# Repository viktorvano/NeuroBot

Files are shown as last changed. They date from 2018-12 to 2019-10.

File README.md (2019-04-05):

# NeuroBot
This is open source robot with a deep neural network.
Deep Neural Network can be configured by a file content.

Training Data are in "training.txt".

Topology is in "topology.txt".

Demo video: https://www.youtube.com/watch?v=UL9_z_reCno

Android App: https://play.google.com/store/apps/details?id=com.cyberpunktech.RobotController.app

If the content of "weights.txt" file is deleted, the neural network automatically retrain itself again.
If the number of weights in the weights.txt file matches with topology, the Neural Network just loads them, and runs.

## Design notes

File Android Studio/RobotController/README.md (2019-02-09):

Android BluetoothLeGatt Sample
===================================

This sample demonstrates how to use the Bluetooth LE Generic Attribute Profile (GATT)
to transmit arbitrary data between devices.

Introduction
------------

This sample shows a list of available Bluetooth LE devices and provides
an interface to connect, display data and display GATT services and
characteristics supported by the devices.

It creates a [Service][1] for managing connection and data communication with a GATT server
hosted on a given Bluetooth LE device.

The Activities communicate with the Service, which in turn interacts with the [Bluetooth LE API][2].

[1]:http://developer.android.com/reference/android/app/Service.html
[2]:https://developer.android.com/reference/android/bluetooth/BluetoothGatt.html

Pre-requisites
--------------

- Android Compile SDK: API 26
- Android Build Tools v26.0.0
- Android Min Sdk Version: API 18
- Android Support Repository

Screenshots
-------------

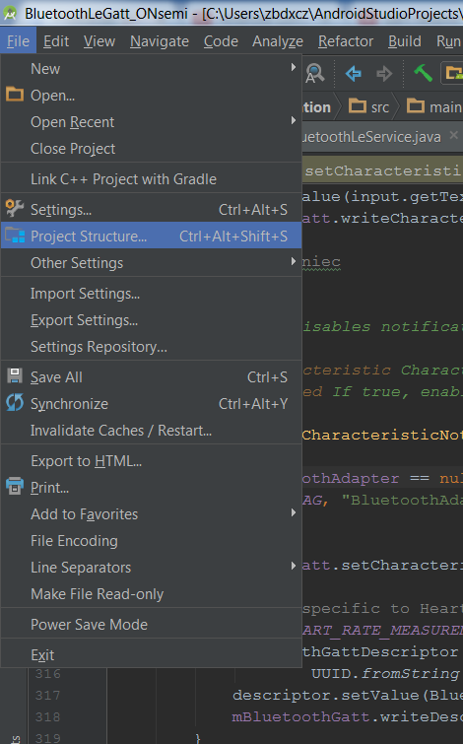
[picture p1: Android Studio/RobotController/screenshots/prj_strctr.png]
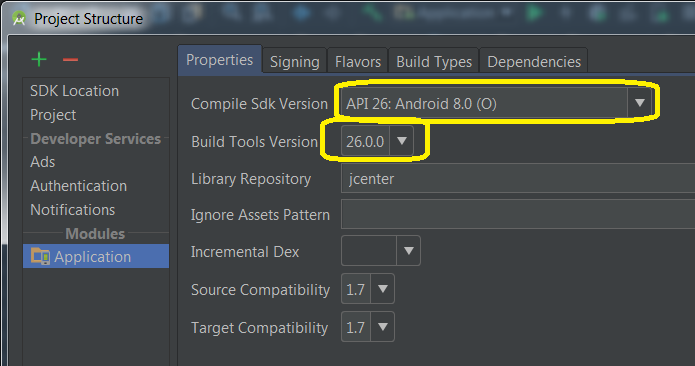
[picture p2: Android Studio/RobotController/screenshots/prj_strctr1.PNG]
 

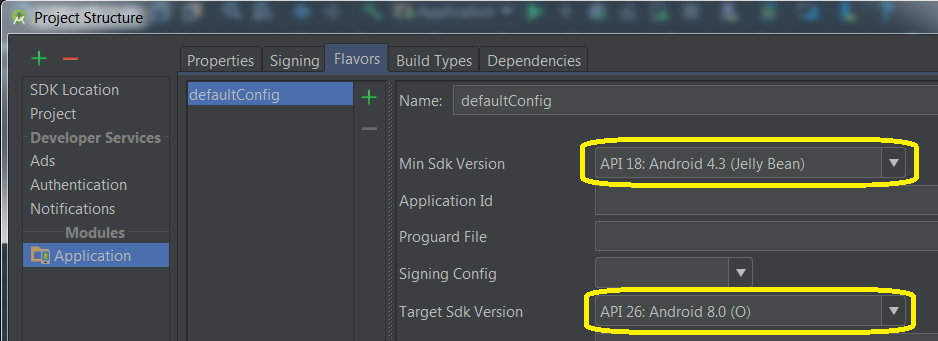
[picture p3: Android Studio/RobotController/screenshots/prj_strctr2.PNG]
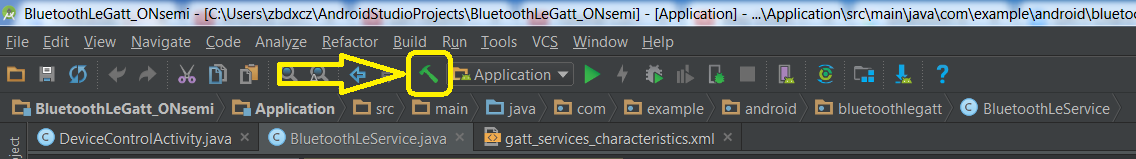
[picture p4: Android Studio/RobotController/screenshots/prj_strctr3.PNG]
 

Getting Started
---------------

This sample uses the Gradle build system. To build this project, use the
"gradlew build" command or use "Import Project" in Android Studio.

Support
-------

- Google+ Community: https://plus.google.com/communities/105153134372062985968
- Stack Overflow: http://stackoverflow.com/questions/tagged/android

Source code origin:
https://github.com/googlesamples/android-BluetoothLeGatt

Patches are encouraged, and may be submitted by forking this project and
submitting a pull request through GitHub. Please see CONTRIBUTING.md for more details.

License
-------

Copyright 2017 The Android Open Source Project, Inc.

Licensed to the Apache Software Foundation (ASF) under one or more contributor
license agreements.  See the NOTICE file distributed with this work for
additional information regarding copyright ownership.  The ASF licenses this
file to you under the Apache License, Version 2.0 (the "License"); you may not
use this file except in compliance with the License.  You may obtain a copy of
the License at

http://www.apache.org/licenses/LICENSE-2.0

Unless required by applicable law or agreed to in writing, software
distributed under the License is distributed on an "AS IS" BASIS, WITHOUT
WARRANTIES OR CONDITIONS OF ANY KIND, either express or implied.  See the
License for the specific language governing permissions and limitations under
the License.

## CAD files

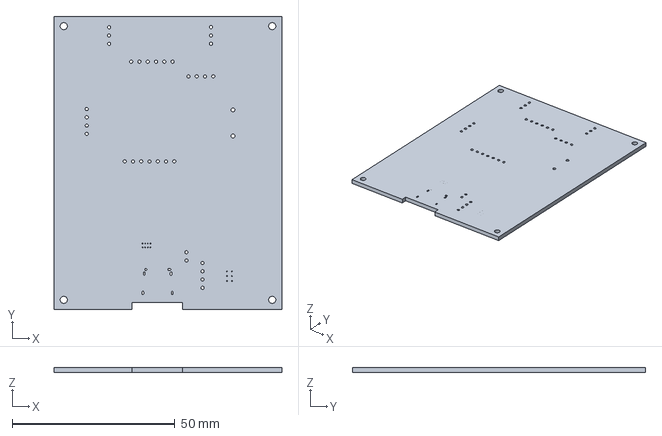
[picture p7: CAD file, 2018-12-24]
KiCad/Neural Robot/NeuralRobot.step
70.0 x 90.0 x 1.60 mm

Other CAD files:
FreeCad/NeuroBot.step
FreeCad/NeuroBot.FCStd
FreeCad/NeuroBot.stl

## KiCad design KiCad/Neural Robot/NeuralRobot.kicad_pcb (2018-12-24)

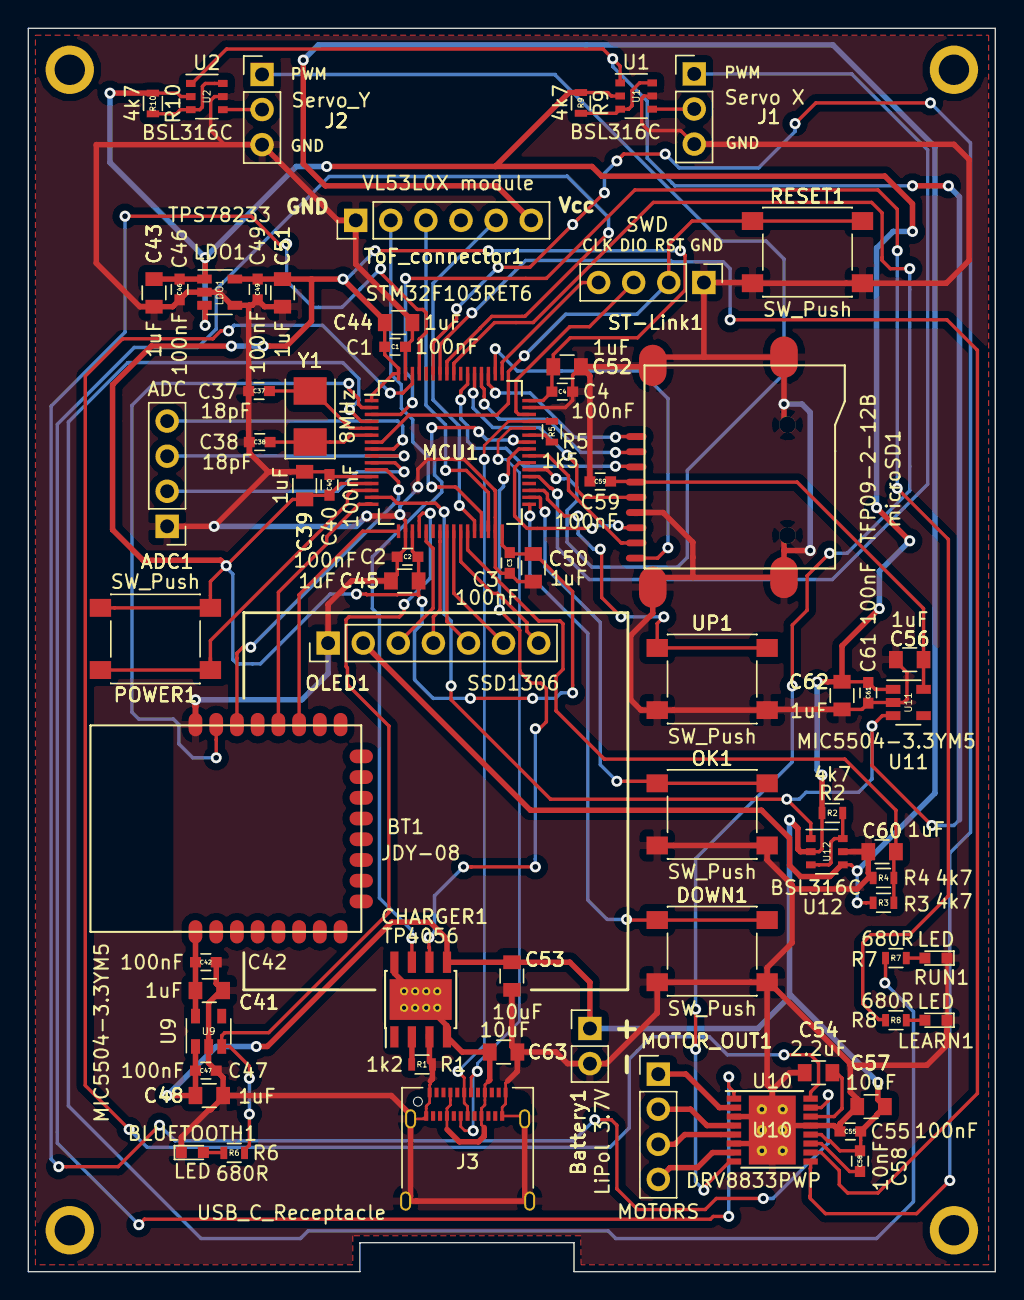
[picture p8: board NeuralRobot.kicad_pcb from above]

Board: 2 copper layers, 70.0 x 90.0 mm, 70 parts (0 on the bottom side), 71 nets.

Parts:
ADC1: ADC; Socket_Strip_Straight_1x04_Pitch2.54mm
BLUETOOTH1: LED; LED_0603
BT1: JDY-08; JDY-08_module
Battery1: LiPol 3.7V; Socket_Strip_Straight_1x02_Pitch2.54mm
C1, C2, C3, C4, C40, C42, C46, C47, C49, C55, C59, C61: 100nF; C_0603
C37, C38: 18pF; C_0603
C39, C41, C43, C44, C45, C48, C50, C51, C52, C56, C60, C62: 1uF; C_0805
C53, C57, C63: 10uF; C_0805
C54: 2.2uF; C_0805
C58: 10nF; C_0603
CHARGER1: TP4056; HTSOP-8-1EP_3.9x4.9mm_Pitch1.27mm_ThermalVias_LargeCopper
DOWN1: SW_Push; SW_SPST_PTS645
J1: Servo X; Socket_Strip_Straight_1x03_Pitch2.54mm
J2: Servo_Y; Socket_Strip_Straight_1x03_Pitch2.54mm
J3: USB_C_Receptacle; USB_C_Receptacle_Amphenol_12401610E4-2A
LDO1: TPS78233; SOT-23-5
LEARN1: LED; LED_0603
MCU1: STM32F103RET6; LQFP-64_10x10mm_Pitch0.5mm
MOTOR_OUT1: MOTORS; Socket_Strip_Straight_1x04_Pitch2.54mm
OK1: SW_Push; SW_SPST_PTS645
OLED1: SSD1306; Socket_Strip_Straight_1x07_Pitch2.54mm
POWER1: SW_Push; SW_SPST_PTS645
R1: 1k2; R_0603
R2, R3, R4, R9, R10: 4k7; R_0603
R5: 1k5; R_0603
R6, R7, R8: 680R; R_0603
RESET1: SW_Push; SW_SPST_PTS645
RUN1: LED; LED_0603
ST-Link1: SWD; Socket_Strip_Straight_1x04_Pitch2.54mm
ToF_connector1: VL53L0X module; Socket_Strip_Straight_1x06_Pitch2.54mm
U1, U2, U12: BSL316C; TSOP-6_1.65x3.05mm_Pitch0.95mm
U9, U11: MIC5504-3.3YM5; SOT-23-5
U10: DRV8833PWP; HTSSOP-16-1EP_4.4x5mm_Pitch0.65mm_ThermalVias
UP1: SW_Push; SW_SPST_PTS645
Y1: 8MHz; Crystal_SMD_5032-2pin_5.0x3.2mm
microSD1: TFP09-2-12B; microSD_card_slot

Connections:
3V3_STM32: C1.2, C2.1, C3.1, C4.1, C39.2, C40.1, C44.2, C45.2, C49.2, C50.2, C51.2, C52.2, LDO1.5, MCU1.1, MCU1.13, MCU1.19, MCU1.32, MCU1.48, MCU1.64, POWER1.2
3V7: Battery1.1, C43.2, C46.2, C47.2, C48.2, C53.2, C55.1, C57.1, C58.2, C61.2, C62.2, CHARGER1.5, LDO1.1, LDO1.3, R2.1, R9.1, R10.1, U1.2, U2.2, U9.1, U10.12, U11.1, U12.2
5V: C63.2, CHARGER1.4, CHARGER1.8, CHARGER1.9, J3.A4, J3.A9, J3.B4, J3.B9
A1: MCU1.62, U10.16
A2: MCU1.61, U10.15
B1: MCU1.59, U10.9
B2: MCU1.58, U10.10
BATTERY_SENSE: C60.2, MCU1.27, R3.1, R4.2
BT_ENABLE: MCU1.20, R6.2, U9.3
BT_PWR: BT1.22, MCU1.11
BT_RST: BT1.23, MCU1.2
BT_Vcc: BT1.1, C41.2, C42.2, U9.5
BUTTON_DOWN: DOWN1.1, MCU1.33
BUTTON_OK: MCU1.34, OK1.1
BUTTON_UP: MCU1.35, UP1.1
CHARGING: CHARGER1.7, MCU1.42
CS: MCU1.26, OLED1.7
D+: J3.A6, J3.B6, MCU1.45, R5.1
D-: J3.A7, J3.B7, MCU1.44
DC: MCU1.25, OLED1.6
FULL: CHARGER1.6, MCU1.41
GND: ADC1.1, BLUETOOTH1.1, BT1.24, Battery1.2, C1.1, C2.2, C3.2, C4.2, C37.2, C38.2, C39.1, C40.2, C41.1, C42.1, C43.1, C44.1, C45.1, C46.1, C47.1, C48.1, C49.1, C50.1, C51.1, C52.1, C53.1, C54.2, C55.2, C56.1, C57.2, C59.1, C60.1, C61.1, C62.1, C63.1, CHARGER1.3, DOWN1.2, J1.3, J2.3, J3.A1, J3.A12, J3.B1, J3.B12, J3.S1, LDO1.2, LDO1.4, LEARN1.1, MCU1.12, MCU1.18, MCU1.31, MCU1.47, MCU1.63, OK1.2, OLED1.1, R1.2, R4.1, RESET1.2, RUN1.1, ST-Link1.1, ToF_connector1.1, U1.5, U2.5, U9.2, U10.3, U10.6, U10.13, U10.17, U11.2, U12.5, UP1.2, microSD1.6, microSD1.10
LED_RUN: MCU1.4, R7.2
LED_TRAINING: MCU1.3, R8.2
MOSFET_ENABLE: MCU1.15, U1.1, U2.1, U11.3, U12.1
MOSFET_OUT: OLED1.2, R3.2, ToF_connector1.6, U12.4
MOSI: MCU1.23, OLED1.4
MOTORS_ENABLE: MCU1.57, U10.1
unnamed: ADC1.2, MCU1.10
unnamed: ADC1.3, MCU1.9
unnamed: ADC1.4, MCU1.8
unnamed: BLUETOOTH1.2, R6.1
unnamed: C37.1, MCU1.5, Y1.2
unnamed: C38.1, MCU1.6, Y1.1
unnamed: C54.1, U10.14
unnamed: CHARGER1.2, R1.1
unnamed: J1.2, U1.4
unnamed: J2.2, U2.4
unnamed: LEARN1.2, R8.1
unnamed: MOTOR_OUT1.1, U10.2
unnamed: MOTOR_OUT1.2, U10.4
unnamed: MOTOR_OUT1.4, U10.7
unnamed: R2.2, U12.3, U12.6
unnamed: R7.1, RUN1.2
unnamed: R9.2, U1.3, U1.6
unnamed: R10.2, U2.3, U2.6
OUT2: MOTOR_OUT1.3, U10.5
PA0: MCU1.14, POWER1.1
PWM_X: J1.1, MCU1.37
PWM_Y: J2.1, MCU1.38
RST: MCU1.24, OLED1.5
RX: BT1.19, MCU1.17
Reset: MCU1.7, RESET1.1, ST-Link1.2
SCK: MCU1.21, OLED1.3
SCL: MCU1.29, ToF_connector1.2
SDA: MCU1.30, ToF_connector1.3
SDIO_CLK: MCU1.53, microSD1.5
SDIO_CMD: MCU1.54, microSD1.3
SDIO_D0: MCU1.39, microSD1.7
SDIO_D1: MCU1.40, microSD1.8
SDIO_D2: MCU1.51, microSD1.1
SDIO_D3: MCU1.52, microSD1.2
SD_DETECTION: MCU1.50, microSD1.9
SD_Vcc: C56.2, C59.2, U11.5, microSD1.4
SWCLK: MCU1.49, ST-Link1.4
SWDIO: MCU1.46, ST-Link1.3
TX: BT1.20, MCU1.16
ToF_Enable: MCU1.28, ToF_connector1.5
USB_ENABLE: MCU1.43, R5.2
VCP: C58.1, U10.11
nFAULT: MCU1.56, U10.8

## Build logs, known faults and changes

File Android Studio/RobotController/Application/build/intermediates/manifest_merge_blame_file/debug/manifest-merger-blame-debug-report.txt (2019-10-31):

1<?xml version="1.0" encoding="utf-8"?>
2<!--
3 Copyright 2013 The Android Open Source Project
4
5 Licensed under the Apache License, Version 2.0 (the "License");
6 you may not use this file except in compliance with the License.
7 You may obtain a copy of the License at
8
9     http://www.apache.org/licenses/LICENSE-2.0
10
11 Unless required by applicable law or agreed to in writing, software
12 distributed under the License is distributed on an "AS IS" BASIS,
13 WITHOUT WARRANTIES OR CONDITIONS OF ANY KIND, either express or implied.
14 See the License for the specific language governing permissions and
15 limitations under the License.
16-->
17<manifest xmlns:android="http://schemas.android.com/apk/res/android"
18    package="com.cyberpunktech.RobotController.app"
19    android:versionCode="7"
20    android:versionName="1.6" >
21
22    <uses-sdk
23        android:minSdkVersion="18"
23-->C:\Users\viktor.vano\Documents\GitHub\NeuroBot\Android Studio\RobotController\Application\src\main\AndroidManifest.xml
24        android:targetSdkVersion="28" />
24-->C:\Users\viktor.vano\Documents\GitHub\NeuroBot\Android Studio\RobotController\Application\src\main\AndroidManifest.xml
25
26    <!-- Min/target SDK versions (<uses-sdk>) managed by build.gradle -->
27
28
29    <!--
30    Declare this required feature if you want to make the app available to BLE-capable
31    devices only.  If you want to make your app available to devices that don't support BLE,
32    you should omit this in the manifest.  Instead, determine BLE capability by using
33    PackageManager.hasSystemFeature(FEATURE_BLUETOOTH_LE)
34    -->
35    <uses-feature
35-->C:\Users\viktor.vano\Documents\GitHub\NeuroBot\Android Studio\RobotController\Application\src\main\AndroidManifest.xml:31:5-89
36        android:name="android.hardware.bluetooth_le"
36-->C:\Users\viktor.vano\Documents\GitHub\NeuroBot\Android Studio\RobotController\Application\src\main\AndroidManifest.xml:31:19-63
37        android:required="true" />
37-->C:\Users\viktor.vano\Documents\GitHub\NeuroBot\Android Studio\RobotController\Application\src\main\AndroidManifest.xml:31:64-87
38
39    <uses-permission android:name="android.permission.BLUETOOTH" />
39-->C:\Users\viktor.vano\Documents\GitHub\NeuroBot\Android Studio\RobotController\Application\src\main\AndroidManifest.xml:33:5-67
39-->C:\Users\viktor.vano\Documents\GitHub\NeuroBot\Android Studio\RobotController\Application\src\main\AndroidManifest.xml:33:22-65
40    <uses-permission android:name="android.permission.BLUETOOTH_ADMIN" />
40-->C:\Users\viktor.vano\Documents\GitHub\NeuroBot\Android Studio\RobotController\Application\src\main\AndroidManifest.xml:34:5-73
40-->C:\Users\viktor.vano\Documents\GitHub\NeuroBot\Android Studio\RobotController\Application\src\main\AndroidManifest.xml:34:22-71
41    <uses-permission android:name="android.permission.ACCESS_COARSE_LOCATION" />
41-->C:\Users\viktor.vano\Documents\GitHub\NeuroBot\Android Studio\RobotController\Application\src\main\AndroidManifest.xml:35:5-81
41-->C:\Users\viktor.vano\Documents\GitHub\NeuroBot\Android Studio\RobotController\Application\src\main\AndroidManifest.xml:35:22-78
42    <uses-permission android:name="android.permission.ACCESS_FINE_LOCATION" />
42-->C:\Users\viktor.vano\Documents\GitHub\NeuroBot\Android Studio\RobotController\Application\src\main\AndroidManifest.xml:36:5-79
42-->C:\Users\viktor.vano\Documents\GitHub\NeuroBot\Android Studio\RobotController\Application\src\main\AndroidManifest.xml:36:22-76
43
44    <application
44-->C:\Users\viktor.vano\Documents\GitHub\NeuroBot\Android Studio\RobotController\Application\src\main\AndroidManifest.xml:40:5-56:19
45        android:appComponentFactory="android.support.v4.app.CoreComponentFactory"
45-->[com.android.support:support-compat:28.0.0] C:\Users\viktor.vano\.gradle\caches\transforms-2\files-2.1\ccf94a4f227dfa4f17156620e28a8b98\support-compat-28.0.0\AndroidManifest.xml:22:18-91
46        android:debuggable="true"
47        android:icon="@drawable/ic_launcher"
47-->C:\Users\viktor.vano\Documents\GitHub\NeuroBot\Android Studio\RobotController\Application\src\main\AndroidManifest.xml:41:9-45
48        android:label="Robot Controller"
48-->C:\Users\viktor.vano\Documents\GitHub\NeuroBot\Android Studio\RobotController\Application\src\main\AndroidManifest.xml:40:18-50
49        android:testOnly="true"
50        android:theme="@android:style/Theme.Holo.Light" >
50-->C:\Users\viktor.vano\Documents\GitHub\NeuroBot\Android Studio\RobotController\Application\src\main\AndroidManifest.xml:42:9-56
51        <activity
51-->C:\Users\viktor.vano\Documents\GitHub\NeuroBot\Android Studio\RobotController\Application\src\main\AndroidManifest.xml:43:9-51:20
52            android:name="com.cyberpunktech.RobotController.app.DeviceScanActivity"
52-->C:\Users\viktor.vano\Documents\GitHub\NeuroBot\Android Studio\RobotController\Application\src\main\AndroidManifest.xml:43:19-90
53            android:configChanges="orientation"
53-->C:\Users\viktor.vano\Documents\GitHub\NeuroBot\Android Studio\RobotController\Application\src\main\AndroidManifest.xml:45:13-48
54            android:label="Robot Controller"
54-->C:\Users\viktor.vano\Documents\GitHub\NeuroBot\Android Studio\RobotController\Application\src\main\AndroidManifest.xml:44:13-45
55            android:screenOrientation="portrait" >
55-->C:\Users\viktor.vano\Documents\GitHub\NeuroBot\Android Studio\RobotController\Application\src\main\AndroidManifest.xml:46:13-49
56            <intent-filter>
56-->C:\Users\viktor.vano\Documents\GitHub\NeuroBot\Android Studio\RobotController\Application\src\main\AndroidManifest.xml:47:13-50:29
57                <action android:name="android.intent.action.MAIN" />
57-->C:\Users\viktor.vano\Documents\GitHub\NeuroBot\Android Studio\RobotController\Application\src\main\AndroidManifest.xml:48:17-68
57-->C:\Users\viktor.vano\Documents\GitHub\NeuroBot\Android Studio\RobotController\Application\src\main\AndroidManifest.xml:48:25-66
58
59                <category android:name="android.intent.category.LAUNCHER" />
59-->C:\Users\viktor.vano\Documents\GitHub\NeuroBot\Android Studio\RobotController\Application\src\main\AndroidManifest.xml:49:17-76
59-->C:\Users\viktor.vano\Documents\GitHub\NeuroBot\Android Studio\RobotController\Application\src\main\AndroidManifest.xml:49:27-74
60            </intent-filter>
61        </activity>
62        <activity
62-->C:\Users\viktor.vano\Documents\GitHub\NeuroBot\Android Studio\RobotController\Application\src\main\AndroidManifest.xml:52:9-54:51
63            android:name="com.cyberpunktech.RobotController.app.DeviceControlActivity"
63-->C:\Users\viktor.vano\Documents\GitHub\NeuroBot\Android Studio\RobotController\Application\src\main\AndroidManifest.xml:52:19-93
64            android:configChanges="orientation"
64-->C:\Users\viktor.vano\Documents\GitHub\NeuroBot\Android Studio\RobotController\Application\src\main\AndroidManifest.xml:53:13-48
65            android:screenOrientation="portrait" />
65-->C:\Users\viktor.vano\Documents\GitHub\NeuroBot\Android Studio\RobotController\Application\src\main\AndroidManifest.xml:54:13-49
66
67        <service
67-->C:\Users\viktor.vano\Documents\GitHub\NeuroBot\Android Studio\RobotController\Application\src\main\AndroidManifest.xml:55:9-114
68            android:name="com.cyberpunktech.RobotController.app.BluetoothLeService"
68-->C:\Users\viktor.vano\Documents\GitHub\NeuroBot\Android Studio\RobotController\Application\src\main\AndroidManifest.xml:55:18-89
69            android:enabled="true" />
69-->C:\Users\viktor.vano\Documents\GitHub\NeuroBot\Android Studio\RobotController\Application\src\main\AndroidManifest.xml:55:90-112
70    </application>
71
72</manifest>

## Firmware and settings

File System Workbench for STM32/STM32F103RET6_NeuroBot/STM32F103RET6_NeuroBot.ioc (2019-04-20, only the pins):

Mcu.UserName=STM32F103RETx
PA0-WKUP.GPIO_Label=POWER_ON_MAIN
PA0-WKUP.Signal=SYS_WKUP
PA1.GPIO_Label=MOSFET_Enable
PA1.Signal=GPIO_Output
PA10.GPIO_Label=USB_Enable
PA10.Signal=GPIO_Output
PA11.Signal=USB_DM
PA12.Signal=USB_DP
PA13.Signal=SYS_JTMS-SWDIO
PA14.Signal=SYS_JTCK-SWCLK
PA15.GPIO_Label=SD_DETECTION
PA15.Signal=GPIO_Input
PA2.Signal=USART2_TX
PA3.Signal=USART2_RX
PA4.GPIO_Label=Bluetooth_Enable
PA4.Signal=GPIO_Output
PA5.Signal=SPI1_SCK
PA7.Signal=SPI1_MOSI
PA8.GPIO_Label=Battery_Full
PA8.Signal=GPIO_Input
PA9.GPIO_Label=Battery_Charging
PA9.Signal=GPIO_Input
PB0.GPIO_Label=OLED_CS
PB0.Signal=GPIO_Output
PB1.GPIO_Label=BATTERY_SENSE
PB1.Signal=ADCx_IN9
PB10.Signal=I2C2_SCL
PB11.Signal=I2C2_SDA
PB12.GPIO_Label=BUTTON_DOWN
PB12.Signal=GPIO_Input
PB13.GPIO_Label=BUTTON_OK
PB13.Signal=GPIO_Input
PB14.GPIO_Label=BUTTON_UP
PB14.Signal=GPIO_Input
PB2.GPIO_Label=ToF_Enable
PB2.Signal=GPIO_Output
PB4.GPIO_Label=Motor_nFault
PB4.Signal=GPIO_Input
PB5.GPIO_Label=Motor_Enable
PB5.Signal=GPIO_Output
PB6.GPIO_Label=Motor_B2
PB6.Signal=GPIO_Output
PB7.GPIO_Label=Motor_B1
PB7.Signal=GPIO_Output
PB8.GPIO_Label=Motor_A2
PB8.Signal=GPIO_Output
PB9.GPIO_Label=Motor_A1
PB9.Signal=GPIO_Output
PC0.Signal=ADCx_IN10
PC1.Signal=ADCx_IN11
PC10.Signal=SDIO_D2
PC11.Signal=SDIO_D3
PC12.Signal=SDIO_CK
PC13-TAMPER-RTC.GPIO_Label=Bluetooth_RESET
PC13-TAMPER-RTC.Signal=GPIO_Output
PC14-OSC32_IN.GPIO_Label=LED_Training
PC14-OSC32_IN.Signal=GPIO_Output
PC15-OSC32_OUT.GPIO_Label=LED_Run
PC15-OSC32_OUT.Signal=GPIO_Output
PC2.Signal=ADCx_IN12
PC3.GPIO_Label=Bluetooth_PWR
PC3.Signal=GPIO_Output
PC4.GPIO_Label=OLED_RESET
PC4.Signal=GPIO_Output
PC5.GPIO_Label=OLED_DC
PC5.Signal=GPIO_Output
PC6.Signal=S_TIM3_CH1
PC7.Signal=S_TIM3_CH2
PC8.Signal=SDIO_D0
PC9.Signal=SDIO_D1
PD0-OSC_IN.Signal=RCC_OSC_IN
PD1-OSC_OUT.Signal=RCC_OSC_OUT
PD2.Signal=SDIO_CMD

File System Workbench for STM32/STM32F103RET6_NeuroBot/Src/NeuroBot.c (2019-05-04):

/*
 * NeuroBot.c
 *
 *  Created on: Dec 5, 2018
 *      Author: CyberPunkTECH
 */

#include "NeuroBot.h"


char buffer[50];
ButtonStruct OK, UP, DOWN, POWER;
int iDistance;
int model=0, revision=0;
uint8_t menu=0, redraw=1, cnt_flag=0;
uint32_t ADC[4];
float Battery=2500;
int percent=100, percent_old;
FATFS myFAT;
uint16_t connection_cnt=1000, cnt_20ms=250;

void NeuroBot_init()
{
	HAL_TIM_Base_Start(&htim3);
	servoX(0.5f);
	servoY(0.0f);
	HAL_TIM_PWM_Start(&htim3, TIM_CHANNEL_1);
	HAL_TIM_PWM_Start(&htim3, TIM_CHANNEL_2);

	HAL_GPIO_WritePin(MOSFET_Enable_GPIO_Port, MOSFET_Enable_Pin, SET);
	HAL_GPIO_WritePin(ToF_Enable_GPIO_Port, ToF_Enable_Pin, SET);
	while(I2C2->SR2==2)
	{
	  while(HAL_I2C_DeInit(&hi2c2)!=HAL_OK);
	  while(HAL_I2C_Init(&hi2c2)!=HAL_OK);
	}
	tofInit(1); // set long range mode (up to 2m)
	tofGetModel(&model, &revision);
	iDistance = tofReadDistance();
	while(model!=238 || revision!=16)
	{
	  while(HAL_I2C_DeInit(&hi2c2)!=HAL_OK);
	  while(HAL_I2C_Init(&hi2c2)!=HAL_OK);
	  tofInit(1); // set long range mode (up to 2m)
	  tofGetModel(&model, &revision);
	  iDistance = tofReadDistance();
	}
	HAL_TIM_Base_Start_IT(&htim2);

	HAL_ADC_Start_DMA(&hadc1, (uint32_t*)ADC,4);
	HAL_ADC_Start_IT(&hadc1);

	ssd1306_Init();
	ssd1306_Fill(Black);
	ssd1306_SetCursor(30, 0);
	ssd1306_WriteString("Hello", Font_11x18, White);
	ssd1306_SetCursor(35, 20);
	ssd1306_WriteString("I am", Font_11x18, White);
	ssd1306_SetCursor(20, 40);
	ssd1306_WriteString("NeuroBot", Font_11x18, White);
	ssd1306_UpdateScreen();

	memset(buffer, 0, sizeof(buffer));
	__HAL_UART_DISABLE_IT(&huart2, UART_IT_RXNE);
	GPIO_POWER_Init();
	HAL_Delay(2000);
	buttons_release();

	HAL_GPIO_WritePin(Motor_Enable_GPIO_Port, Motor_Enable_Pin, SET);
	HAL_GPIO_WritePin(Bluetooth_Enable_GPIO_Port, Bluetooth_Enable_Pin, RESET);
	HAL_GPIO_WritePin(LED_Training_GPIO_Port, LED_Training_Pin, RESET);
	HAL_GPIO_WritePin(LED_Run_GPIO_Port, LED_Run_Pin, RESET);
	if(!HAL_GPIO_ReadPin(SD_DETECTION_GPIO_Port, SD_DETECTION_Pin))
	{
		int temp=0;
	  hsd.Init.ClockDiv = 36;
	  while(HAL_SD_Init(&hsd, &SDCardInfo)!=SD_OK)
	  {
		  temp++;
		  HAL_Delay(100);
		  if(temp>=30)
			  NeuroBot_sleep();
	  }
	  temp=0;
	  while(HAL_SD_WideBusOperation_Config(&hsd, SDIO_BUS_WIDE_4B))
	  {
		  temp++;
		  HAL_Delay(100);
		  if(temp>=30)
			  NeuroBot_sleep();
	  }
	}else
	{
		ssd1306_Fill(Black);
		ssd1306_SetCursor(2, 26);
		ssd1306_WriteString("Insert SD", Font_11x18, White);
		ssd1306_SetCursor(2, 26+18);
		ssd1306_WriteString("Press OK to OFF.", Font_7x10, White);
		ssd1306_UpdateScreen();
		while(!OK.released);
		NeuroBot_sleep();
	}

	uint8_t attempts=0;
	while(1)
	{
		attempts++;
		if(f_mount(&myFAT, SD_Path, 1)==FR_OK)
			break;
		if(attempts>10)
			NeuroBot_sleep();
		HAL_Delay(150);
	}

	percent_old=percent;
}

void servoY(float value)
{
	if(value<=0.0f)
		value=0.0f;
	__HAL_TIM_SetCompare(&htim3, TIM_CHANNEL_2, 51+(value*52.0f));
}

void servoX(float value)
{
	if(value<=0.0f)
		value=0.0f;
	__HAL_TIM_SetCompare(&htim3, TIM_CHANNEL_1, 33+(value*80.0f));
}

float measure_distance()
{
	iDistance = tofReadDistance();
	if(iDistance>2000)
	{
		iDistance=2000;
	}else
	if(iDistance<0)
	{
		iDistance=0;
	}

	return (float)iDistance/2000.0f;
}

uint8_t string_compare(char array1[], char array2[], uint16_t lenght)
{
	 uint8_t comVAR=0, i;
	 for(i=0;i<lenght;i++)
	   	{
	   		  if(array1[i]==array2[i])
	   	  		  comVAR++;
	   	  	  else comVAR=0;
	   	}
	 if (comVAR==lenght)
		 	return 1;
	 else 	return 0;
}

void Message_handler()
{
	if(string_compare(buffer, "stop", strlen("stop")))
	{
		motor_stop();
	}else
	if(string_compare(buffer, "forward", strlen("forward")))
	{
		motorA_forward();
		motorB_forward();
	}else
	if(string_compare(buffer, "backward", strlen("backward")))
	{
		motorA_backward();
		motorB_backward();
	}else
	if(string_compare(buffer, "right", strlen("right")))
	{
		motorA_forward();
		motorB_backward();
	}else
	if(string_compare(buffer, "left", strlen("left")))
	{
		motorA_backward();
		motorB_forward();
	}
}

void overheat_check()
{
	if(!HAL_GPIO_ReadPin(Motor_nFault_GPIO_Port, Motor_nFault_Pin))//overheat
	{
		HAL_GPIO_WritePin(Motor_A1_GPIO_Port, Motor_A1_Pin, 0);
		HAL_GPIO_WritePin(Motor_A2_GPIO_Port, Motor_A2_Pin, 0);
		HAL_GPIO_WritePin(Motor_B1_GPIO_Port, Motor_B1_Pin, 0);
		HAL_GPIO_WritePin(Motor_B2_GPIO_Port, Motor_B2_Pin, 0);
		ssd1306_Fill(Black);
		ssd1306_SetCursor(30, 0);
		ssd1306_WriteString("Motor", Font_11x18, White);
		ssd1306_SetCursor(35, 20);
		ssd1306_WriteString("driver", Font_11x18, White);
		ssd1306_SetCursor(20, 40);
		ssd1306_WriteString("overheat", Font_11x18, White);
		ssd1306_UpdateScreen();
		while(!HAL_GPIO_ReadPin(Motor_nFault_GPIO_Port, Motor_nFault_Pin));
	}
}

void motor_stop()
{
	  HAL_GPIO_WritePin(Motor_A1_GPIO_Port, Motor_A1_Pin, 0);
	  HAL_GPIO_WritePin(Motor_A2_GPIO_Port, Motor_A2_Pin, 0);
	  HAL_GPIO_WritePin(Motor_B1_GPIO_Port, Motor_B1_Pin, 0);
	  HAL_GPIO_WritePin(Motor_B2_GPIO_Port, Motor_B2_Pin, 0);
	  overheat_check();
}

void motorA_forward()
{
	  HAL_GPIO_WritePin(Motor_A1_GPIO_Port, Motor_A1_Pin, 1);
	  HAL_GPIO_WritePin(Motor_A2_GPIO_Port, Motor_A2_Pin, 0);
}

void motorA_backward()
{
	  HAL_GPIO_WritePin(Motor_A1_GPIO_Port, Motor_A1_Pin, 0);
	  HAL_GPIO_WritePin(Motor_A2_GPIO_Port, Motor_A2_Pin, 1);
}

void motorA_stop()
{
	  HAL_GPIO_WritePin(Motor_A1_GPIO_Port, Motor_A1_Pin, 0);
	  HAL_GPIO_WritePin(Motor_A2_GPIO_Port, Motor_A2_Pin, 0);
}

void motorB_forward()
{
	  HAL_GPIO_WritePin(Motor_B1_GPIO_Port, Motor_B1_Pin, 1);
	  HAL_GPIO_WritePin(Motor_B2_GPIO_Port, Motor_B2_Pin, 0);
}

void motorB_backward()
{
	  HAL_GPIO_WritePin(Motor_B1_GPIO_Port, Motor_B1_Pin, 0);
	  HAL_GPIO_WritePin(Motor_B2_GPIO_Port, Motor_B2_Pin, 1);
}

void motorB_stop()
{
	  HAL_GPIO_WritePin(Motor_B1_GPIO_Port, Motor_B1_Pin, 0);
	  HAL_GPIO_WritePin(Motor_B2_GPIO_Port, Motor_B2_Pin, 0);
}
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

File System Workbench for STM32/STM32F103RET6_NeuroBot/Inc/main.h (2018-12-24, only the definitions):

#define Bluetooth_RESET_Pin GPIO_PIN_13
#define Bluetooth_RESET_GPIO_Port GPIOC
#define LED_Training_Pin GPIO_PIN_14
#define LED_Training_GPIO_Port GPIOC
#define LED_Run_Pin GPIO_PIN_15
#define LED_Run_GPIO_Port GPIOC
#define Bluetooth_PWR_Pin GPIO_PIN_3
#define Bluetooth_PWR_GPIO_Port GPIOC
#define POWER_ON_MAIN_Pin GPIO_PIN_0
#define POWER_ON_MAIN_GPIO_Port GPIOA
#define MOSFET_Enable_Pin GPIO_PIN_1
#define MOSFET_Enable_GPIO_Port GPIOA
#define Bluetooth_Enable_Pin GPIO_PIN_4
#define Bluetooth_Enable_GPIO_Port GPIOA
#define OLED_RESET_Pin GPIO_PIN_4
#define OLED_RESET_GPIO_Port GPIOC
#define OLED_DC_Pin GPIO_PIN_5
#define OLED_DC_GPIO_Port GPIOC
#define OLED_CS_Pin GPIO_PIN_0
#define OLED_CS_GPIO_Port GPIOB
#define BATTERY_SENSE_Pin GPIO_PIN_1
#define BATTERY_SENSE_GPIO_Port GPIOB
#define ToF_Enable_Pin GPIO_PIN_2
#define ToF_Enable_GPIO_Port GPIOB
#define BUTTON_DOWN_Pin GPIO_PIN_12
#define BUTTON_DOWN_GPIO_Port GPIOB
#define BUTTON_OK_Pin GPIO_PIN_13
#define BUTTON_OK_GPIO_Port GPIOB
#define BUTTON_UP_Pin GPIO_PIN_14
#define BUTTON_UP_GPIO_Port GPIOB
#define Battery_Full_Pin GPIO_PIN_8
#define Battery_Full_GPIO_Port GPIOA
#define Battery_Charging_Pin GPIO_PIN_9
#define Battery_Charging_GPIO_Port GPIOA
#define USB_Enable_Pin GPIO_PIN_10
#define USB_Enable_GPIO_Port GPIOA
#define SD_DETECTION_Pin GPIO_PIN_15
#define SD_DETECTION_GPIO_Port GPIOA
#define Motor_nFault_Pin GPIO_PIN_4
#define Motor_nFault_GPIO_Port GPIOB
#define Motor_Enable_Pin GPIO_PIN_5
#define Motor_Enable_GPIO_Port GPIOB
#define Motor_B2_Pin GPIO_PIN_6
#define Motor_B2_GPIO_Port GPIOB
#define Motor_B1_Pin GPIO_PIN_7
#define Motor_B1_GPIO_Port GPIOB
#define Motor_A2_Pin GPIO_PIN_8
#define Motor_A2_GPIO_Port GPIOB
#define Motor_A1_Pin GPIO_PIN_9
#define Motor_A1_GPIO_Port GPIOB

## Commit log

2018-12-24 First upload
    it contains Cpp project for Visual Studio, System Workbench, and PCB project for KiCad
    [HC06.xlsx, Neural Robot-2018-09-08-19-01-07.sch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]
2018-12-25 Updated projects, added FreCad
    Added FreeCad project, updated Android App, and SWforSTM32.
    Now it sends a message via Bluetooth every 100 ms.
    [NeuroBot.FCStd, NeuroBot.step, NeuroBot.stl]
2018-12-25 3D model update
    Updated FreeCad 3D model for NeuroBot.
    [NeuroBot.FCStd, NeuroBot.step, NeuroBot.stl]
2019-01-11 STM code update
    Updated code for NeuroBot for STM32.
2019-01-11 Updated Freecad Model
    Now it fits well.
    [NeuroBot.FCStd, NeuroBot.step, NeuroBot.stl]
2019-01-11 Updated battery
    Updated max battery level condition.
2019-01-12 Updated battery code
    Now it shows a battery accurately.
2019-01-12 Battery update
    Better coeficient, to calculate voltage.
2019-01-21 Fall detection
    Now it tilts down ToF sensor to avoid a fall from the edge.
    [NeuroBot.c]
2019-01-30 Android update
    Now BLE scan, works on new Android devices.
2019-02-04 Servo tuning
    I just tuned the X servo to the middle.
2019-02-10 FIxed DMA and Battery issue
    I forgot to add 4th ADC to DMA, so those ADC measurements were mixing in a bigger buffer for DMA.
    Now it is fixed.
    [NeuroBot.c, STM32F103RET6_NeuroBot.ioc]
2019-03-03 Battery update
    just lowered down the full bettery voltage, because of the load on the cell during rung mode.
    [STM32F103RET6_NeuroBot.xml]
2019-03-24 Fixed typo
    targerValue to targetValue
    [Neural_Network.cpp]
2019-03-30 Changed ADC sampling
    This will unload the DMA from too many interrupts.
2019-04-20 overheat check
    moved a function to more reasonable place
    [NeuroBot.c, STM32F103RET6_NeuroBot.ioc]
2019-04-20 fixed battery bug
    Now it should refresh battery status after unplugging the charging cable automatically.
    [NeuroBot.c]
2019-04-20 motor_direction()
    Modified the function a little bit.
    Works the same, looks better.
2019-04-24 Print output
    Now it prints outputs of Neural Net for left left motor and right motor. They are marked as L: 0.995 and R: 0.423
    [STM32F103RET6_NeuroBot Run.cfg]
2019-04-30 SD files update
    Now the "Neural Network.exe" prints out a training time.
    Also I have used a more complex topology.
2019-05-04 Updated motor function
    Now the robot can turn more accordingly to its decision.
2019-05-04 Tuned the turning time.
    It was turning too much before.
    [NeuroBot.c]
2019-10-31 Updated to 1.6
    Changed Accelerometer to Gravity sensor.

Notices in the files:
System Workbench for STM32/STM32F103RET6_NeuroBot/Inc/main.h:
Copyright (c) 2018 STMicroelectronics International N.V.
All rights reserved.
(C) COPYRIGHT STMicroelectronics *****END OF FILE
